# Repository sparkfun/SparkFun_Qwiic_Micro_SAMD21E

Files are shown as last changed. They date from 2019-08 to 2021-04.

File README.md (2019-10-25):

SparkFun Qwiic Micro - SAMD21E
========================================

SAMD21 Qwiic Micro (https://www.sparkfun.com/products/15423)

[*SparkFun Qwiic Micro - SAMD21E (DEV-15423)*](https://www.sparkfun.com/products/15423)

Looking for a super small microcontroller to use with the [Qwiic eco-system](https://www.sparkfun.com/qwiic)? The SparkFun Qwiic Micro is molded to fit our standard 1"x1" Qwiic standard size which makes it one of our smallest micro-controller offerings to date. At it's core is the powerful and versatile ATSAMD21E18, which is an ARM Cortex M0+, 32-bit microcontroller, with 256KB of flash memory that can run at up to 48MHz! It has 12 digital pins which include 5 analog pins, SPI, I²C, and an additional UART data bus as well as a Qwiic connector for easy integration into the Qwiic ecosystem and I²C prototyping.

On the underside of the Qwiic Micro, we've left open pads for a LiPo Battery connector that you can add yourself, if you wish you can make the micro-controller portable. We've also provided pads on the underside for a flash memory chip to maximize the board's memory capacity. The SparkFun Qwiic Micro comes programmed with a UF2 Bootloader making it easy to program with easy driver installation! If you need a tiny but mighty micro-controller for you next project check out the SparkFun Qwiic Micro.

Repository Contents
-------------------

* **/Documentation** - Data sheets, additional product information
* **/Hardware** - Eagle design files (.brd, .sch)
* **/Firmware** - UF2 Bootloader and Arduino Board Files
* **/Production** - Production panel files (.brd)

Documentation
--------------
* **[Hookup Guide](https://learn.sparkfun.com/tutorials/sparkfun-qwiic-micro-samd21e-hookup-guide)** - Basic hookup guide for the Qwiic Micro
* **[Graphical Datasheet](https://github.com/sparkfun/Graphical_Datasheets)** - Graphical datasheet for Qwiic Micro can be found in this repo
* **[Qwiic Ecosystem](https://www.sparkfun.com/qwiic)** - Qwiic enabled for fast prototyping!

License Information
-------------------

This product is _**open source**_! 

Please review the LICENSE.md file for license information. 

If you have any questions or concerns on licensing, please contact technical support on our [SparkFun forums](https://forum.sparkfun.com/viewforum.php?f=152).

Distributed as-is; no warranty is given.

- Your friends at SparkFun.

_<COLLABORATION CREDIT>_

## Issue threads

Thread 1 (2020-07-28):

Pin D16 and D17 are swapped in Board variants.h

NikilXYZ, 2020-07-28:
### Subject of the issue
Pin D16 and D17 are swapped.

### Your workbench
* Using board definition pack 1.7.5

### Steps to reproduce
Go to the variant.cpp file. The 16th entry corresponds to PA22 and 17th to PA23.
According to your [graphical datasheet](https://cdn.sparkfun.com/assets/learn_tutorials/9/1/7/Qwiic_Micro_Graphical_Datasheet.pdf) and your schematic, Pin D16 is PA23 and Pin D17 is PA22.
One of the reviews for this board also noticed the error.

### Expected behaviour
If I `digitalWrite(16, HIGH)` it should turns on Pin 16. `digitalWrite(17, HIGH)` should turn on Pin 17.

### Actual behaviour
Right now, if I `digitalWrite(16, HIGH)` it turns on Pin 17 and `digitalWrite(17, HIGH)` turns on Pin 16.

### Steps to resolve
Go to the variant.cpp file, and flip the 16th entry and 17th entry in the pingroup array.
I did this locally and it works fine, but I cannot tell 100 high school students to go do this.

I can make a pull request if needed

edspark, 2020-07-29:
Thanks for the pull request, it has been merged. As I mentioned in the pull request, I still have to update and do a new release of our Arduino Boards repository before you see it on the Arduino side.

Closed 2020-07-29.

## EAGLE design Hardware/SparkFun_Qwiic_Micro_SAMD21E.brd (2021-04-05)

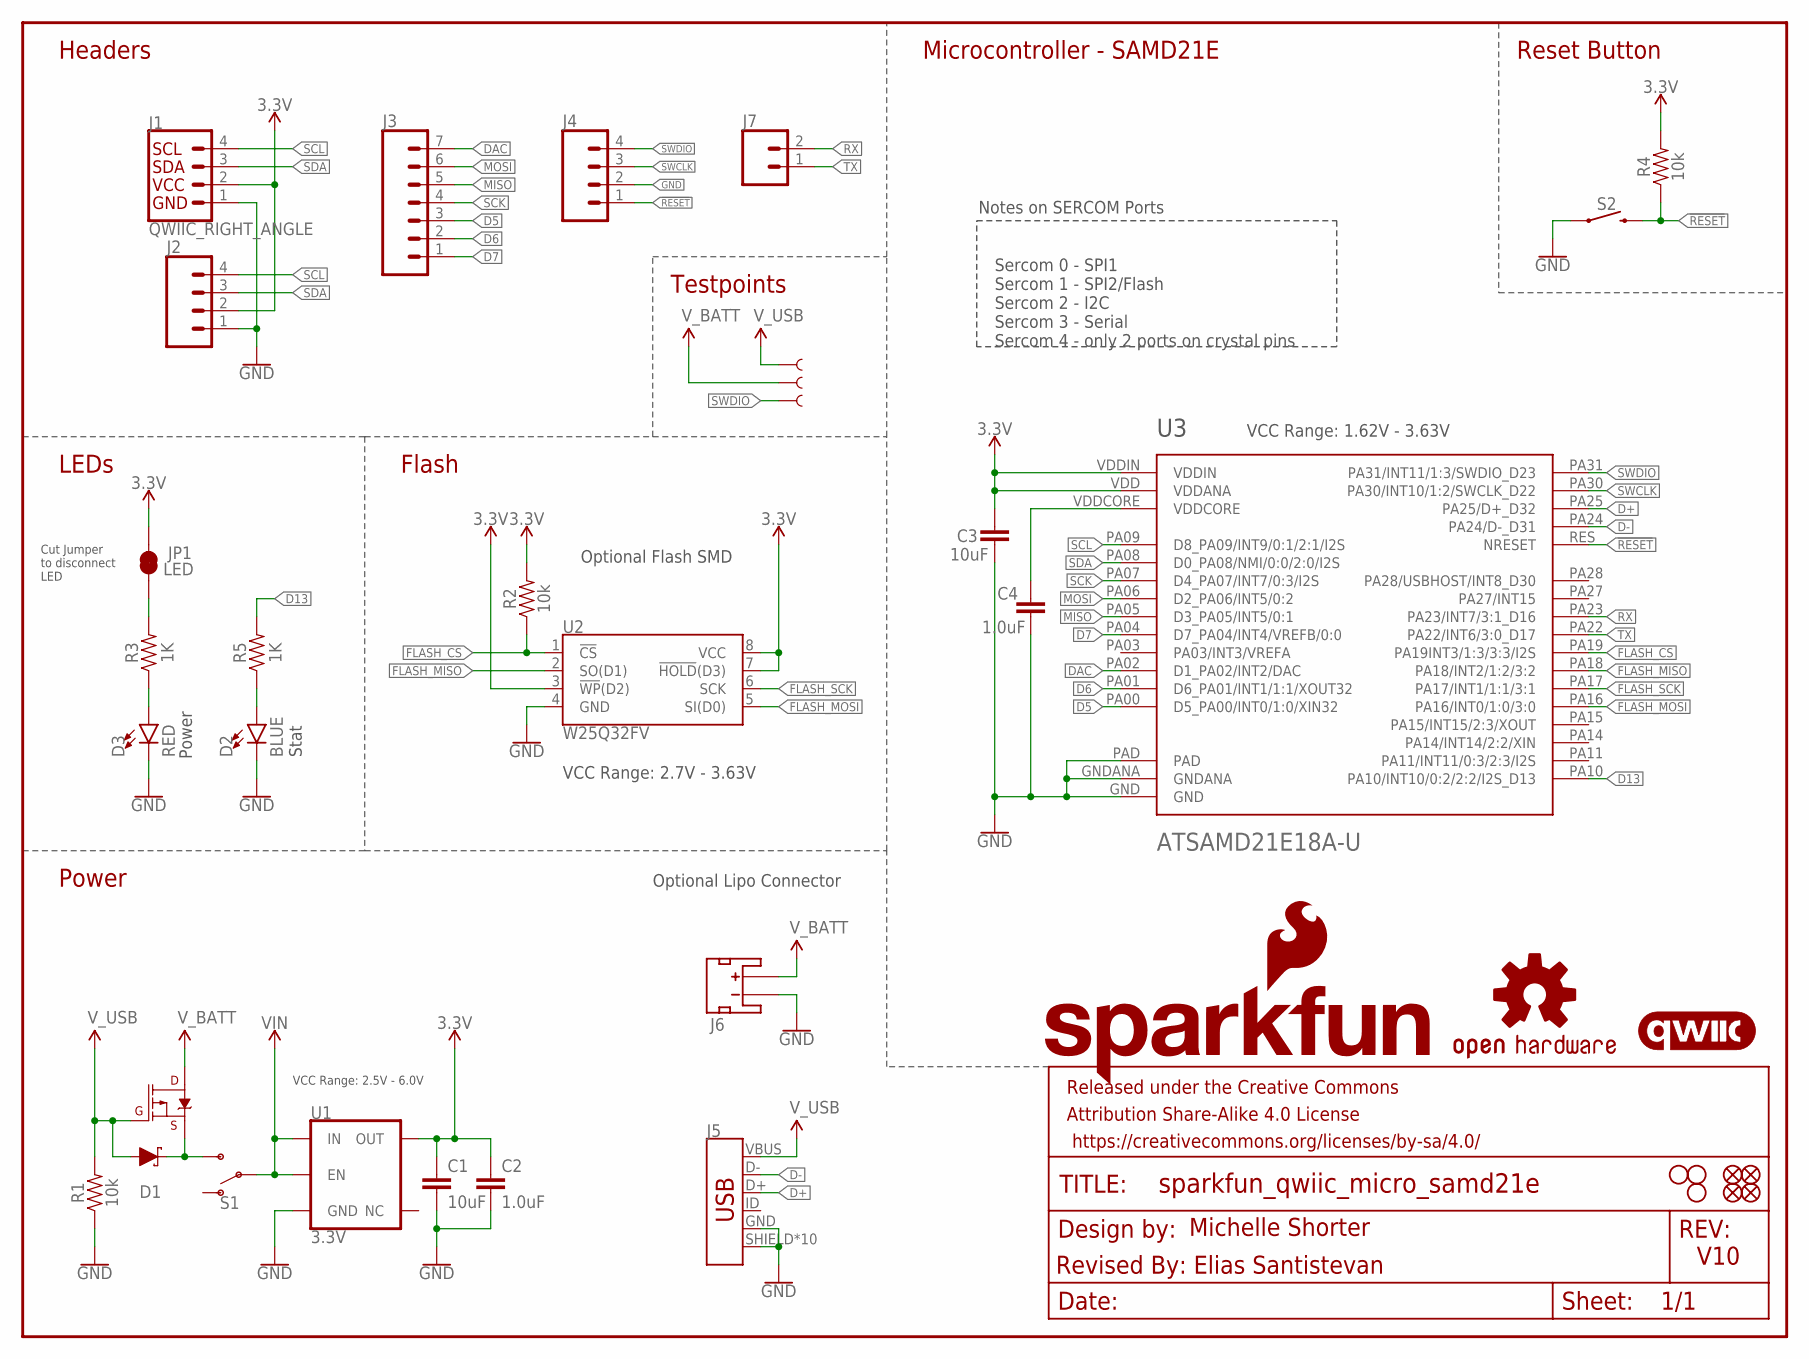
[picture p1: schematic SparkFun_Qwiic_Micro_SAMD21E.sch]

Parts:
C1, C3: 10uF; 0603
C2, C4: 1.0uF; 0402
D1: 1A/23V/620mV; SOD-323
D2: BLUE; LED-0603
D3: RED; LED-0603
FD1, FD2, FD3, FD4: FIDUCIALUFIDUCIAL; FIDUCIAL-MICRO
FRAME1: FRAME-LETTER; CREATIVE_COMMONS
H1, H2, H3: STAND-OFF
J1: QWIIC_RIGHT_ANGLE; JST04_1MM_RA
J2: CONN_041X04_NO_SILK; 1X04_NO_SILK
J3: CONN_07NO_SILK; 1X07_NO_SILK
J4: CONN_041.27MM_NO_SILK; 1X04_1.27MM_NO_SILK
J5: USB_MICRO-B_HALF_PTH_MILL; USB-MICROB-PTH-MILL
J6: JST_2MM_MALE; JST-2-SMD
J7: CONN_021X02_NO_SILK; 1X02_NO_SILK
JP1: LED; SMT-JUMPER_2_NC_TRACE_SILK
LOGO1: SFE_LOGO_NAME.1_INCH; SFE_LOGO_NAME_.1
LOGO2: SFE_LOGO_FLAME.2_INCH; SFE_LOGO_FLAME_.2
LOGO3: OSHW-LOGOS; OSHW-LOGO-S
LOGO4: QWIIC_LOGO_3MM; QWIIC_3MM
Q1: 3.1A/30V/105mΩ; SOT23-3
R1, R2, R4: 10k; 0402
R3, R5: 1K; 0402
S1: SWITCH-SPDT-SMD-RIGHT-ANGLE; SWITCH_SPST_SMD_A
S2: MOMENTARY-SWITCH-SPST-SMD-4.6X2.8MM; TACTILE_SWITCH_SMD_4.6X2.8MM
TP1, TP2, TP3: TEST-POINTTP_15TH_THRU; TP_15TH
U1: 3.3V; SOT23-5
U2: W25Q32FV; SOIC-8
U3: ATSAMD21E18A-U; QFN-32_SAMD

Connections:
3.3V: C1.1, C2.1, C3.1, J1.2, J2.2, JP1.2, R2.2, R4.2, U1.5 (OUT), U2.3 (!WP!(D2)), U2.7 (!HOLD!(D3)), U2.8 (VCC), U3.VDD (VDDANA), U3.VDDIN
!RESET: J4.1, R4.1, S2.3 (2), S2.4 (2), U3.RES (NRESET)
D5: J3.3, U3.PA00 (D5_PA00/INT0/1:0/XIN32)
D6: J3.2, U3.PA01 (D6_PA01/INT1/1:1/XOUT32)
D7: J3.1, U3.PA04 (D7_PA04/INT4/VREFB/0:0)
D13: R5.2, U3.PA10 (PA10/INT10/0:2/2:2/I2S_D13)
D+: J5.D+, U3.PA25 (PA25/D+_D32)
D-: J5.D-, U3.PA24 (PA24/D-_D31)
DAC: J3.7, U3.PA02 (D1_PA02/INT2/DAC)
FLASH_CS: R2.1, U2.1 (!CS!), U3.PA19 (PA19INT3/1:3/3:3/I2S)
FLASH_MISO: U2.2 (SO(D1)), U3.PA18 (PA18/INT2/1:2/3:2)
FLASH_MOSI: U2.5 (SI(D0)), U3.PA16 (PA16/INT0/1:0/3:0)
FLASH_SCK: U2.6 (SCK), U3.PA17 (PA17/INT1/1:1/3:1)
GND: C1.2, C2.2, C3.2, C4.1, D2.C, D3.C, J1.1, J2.1, J4.2, J5.GND, J5.SHIELD, J5.SHIELD2 (SHIELD), J5.SHIELD3 (SHIELD), J5.SHIELD4 (SHIELD), J5.SHIELD5 (SHIELD), J5.SHIELD6 (SHIELD), J5.SHIELD7 (SHIELD), J5.SHIELD8 (SHIELD), J5.SHIELD9 (SHIELD), J5.SHIELD10 (SHIELD), J6.1 (-), R1.1, S2.1, S2.2 (1), U1.2 (GND), U2.4 (GND), U3.GND, U3.GNDANA, U3.PAD
MISO: J3.5, U3.PA05 (D3_PA05/INT5/0:1)
MOSI: J3.6, U3.PA06 (D2_PA06/INT5/0:2)
unnamed: D3.A, R3.1
unnamed: JP1.1, R3.2
unnamed: D2.A, R5.1
RX: J7.2, U3.PA23 (PA23/INT7/3:1_D16)
SCK: J3.4, U3.PA07 (D4_PA07/INT7/0:3/I2S)
SCL: J1.4, J2.4, U3.PA09 (D8_PA09/INT9/0:1/2:1/I2S)
SDA: J1.3, J2.3, U3.PA08 (D0_PA08/NMI/0:0/2:0/I2S)
SWCLK: J4.3, U3.PA30 (PA30/INT10/1:2/SWCLK_D22)
SWDIO: J4.4, TP3.P$1, U3.PA31 (PA31/INT11/1:3/SWDIO_D23)
TX: J7.1, U3.PA22 (PA22/INT6/3:0_D17)
VDDCORE: C4.2, U3.VDDCORE
VIN: S1.2, U1.1 (IN), U1.3 (EN)
VIN1: D1.C, Q1.2 (S), S1.3 (S)
V_BATT: J6.2 (+), Q1.3 (D), TP2.P$1
V_USB: D1.A, J5.VBUS, Q1.1 (G), R1.2, TP1.P$1

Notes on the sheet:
Sercom 0 - SPI1 Sercom 1 - SPI2/Flash Sercom 2 - I2C Sercom 3 - Serial Sercom 4 - only 2 ports on crystal pins
Headers
LEDs
Power
Microcontroller - SAMD21E
Optional Flash SMD
V10
Michelle Shorter
Revised By: Elias Santistevan
Testpoints
Reset Button
Flash
Cut Jumper to disconnect LED
Notes on SERCOM Ports
Stat
VCC Range: 2.5V - 6.0V
VCC Range: 1.62V - 3.63V
VCC Range: 2.7V - 3.63V
Optional Lipo Connector

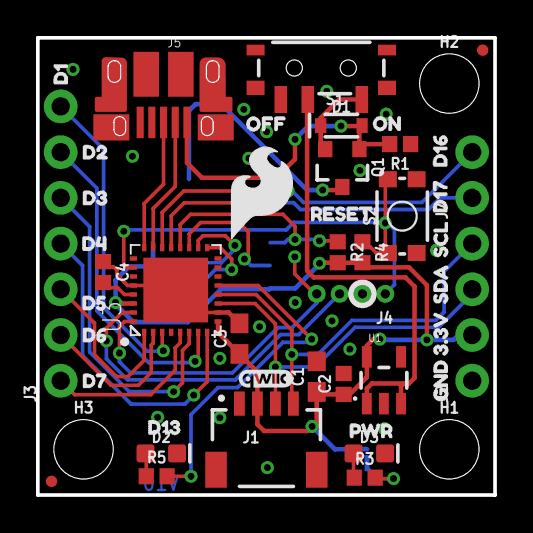
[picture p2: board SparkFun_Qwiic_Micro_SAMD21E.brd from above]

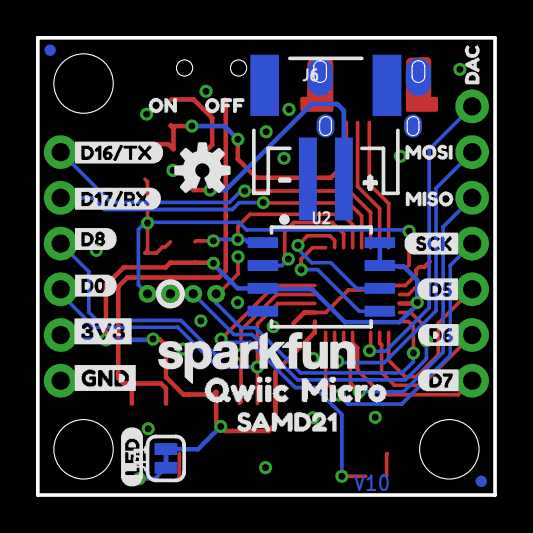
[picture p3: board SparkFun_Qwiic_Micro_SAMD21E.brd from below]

Board: 2 copper layers, 25.4 x 25.4 mm, 80 parts (28 on the bottom side), 31 nets.

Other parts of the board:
U$1: D00
U$2: GND-03
U$3: #23
U$4: #24
U$5: 3#3V10
U$6: D12
U$7: D166
U$8: D177
U$9: D16#TX4
U$10: QWIIC2
U$11: D17#RX3
U$12: D75
U$13: DAC1
U$14: MISO0
U$15: SAMD213
U$16: MOSI2
U$17: 3V3-03
U$18, U$46: ON12
U$19, U$45: OFF13
U$20: SCK7
U$21: RESET0
U$22: D85
U$23: MICRO2
U$24: LED1
U$25: D50
U$26: D61
U$27: D72
U$28: D21
U$29: D136
U$36: D33
U$37: D41
U$38: D52
U$39: D65
U$44: GND11
U$47: PWR16
U$49: SCL8
U$50: SDA9

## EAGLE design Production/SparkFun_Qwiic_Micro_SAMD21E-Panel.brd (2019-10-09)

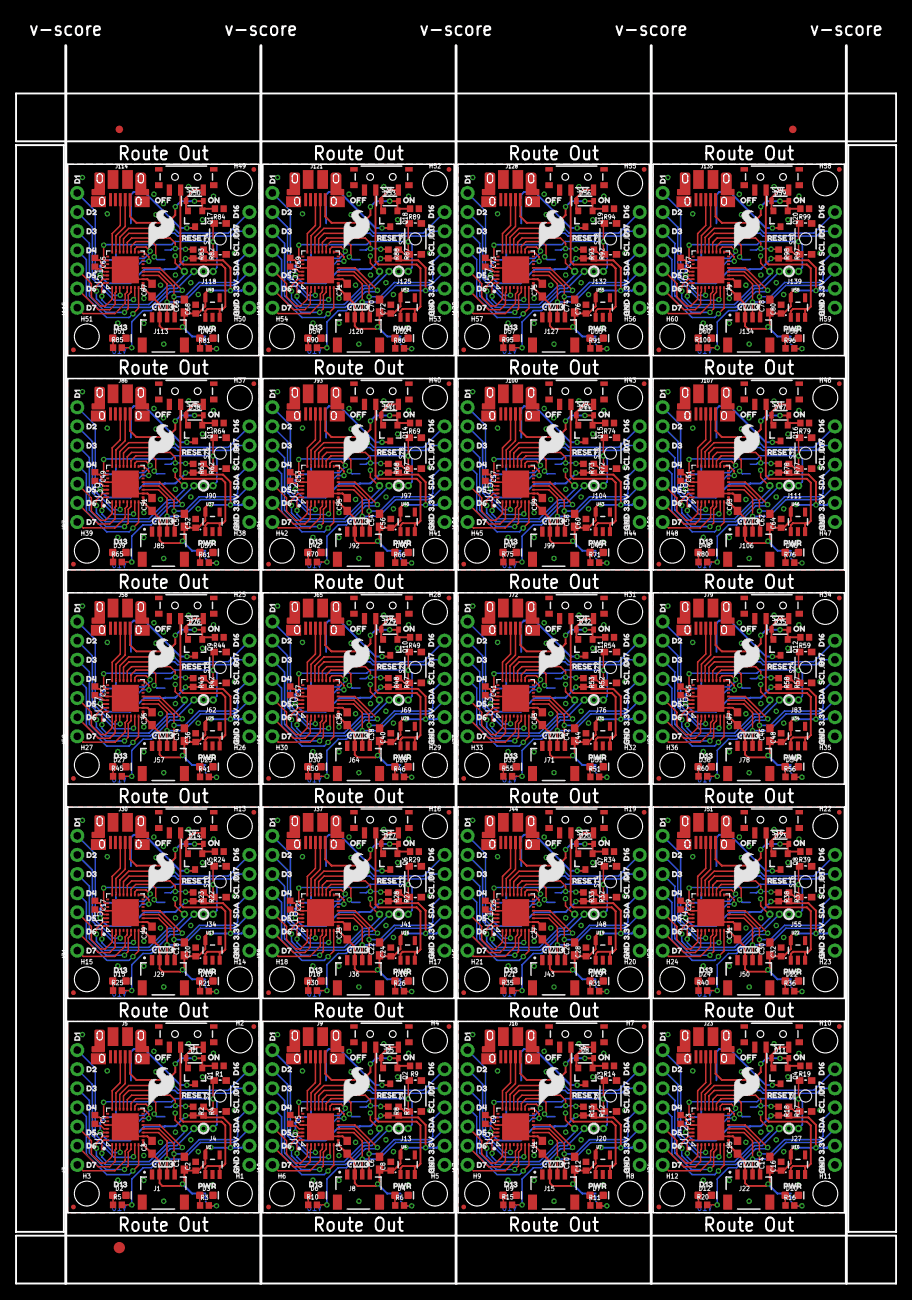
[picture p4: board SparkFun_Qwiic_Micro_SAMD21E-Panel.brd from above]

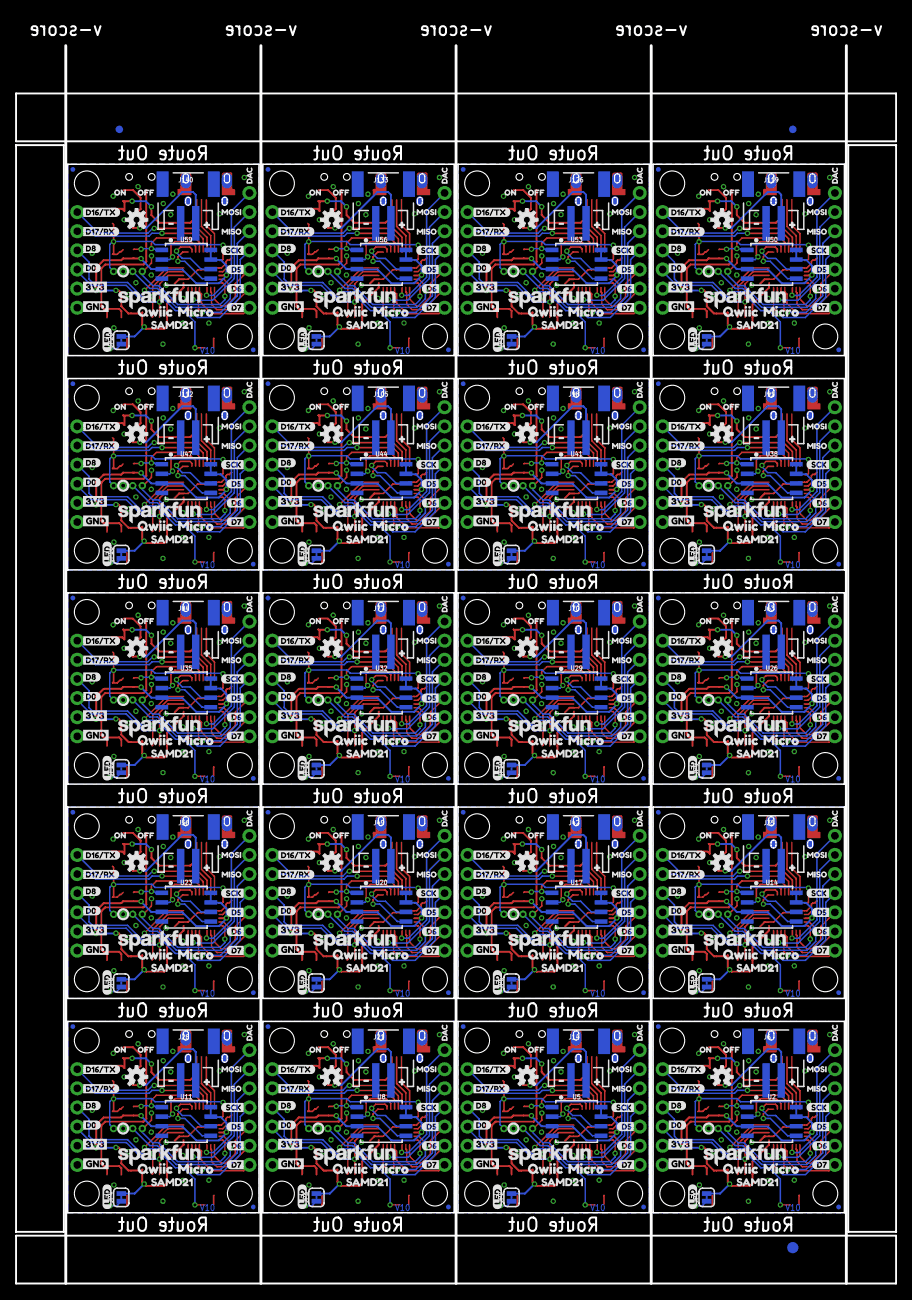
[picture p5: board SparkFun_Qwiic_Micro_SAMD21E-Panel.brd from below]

Board: 2 copper layers, 116.8 x 164.3 mm, 1586 parts (563 on the bottom side), 620 nets.

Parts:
C1, C3, C6, C7, C10, C11, C14, C15, C18, C19, C22, C23, C26, C27, C30, C31, C34, C35, C38, C39, C42, C43, C46, C47, C50, C51, C54, C55, C58, C59, C62, C63, C66, C67, C70, C71, C74, C75, C78, C79: 10uF; 0603
C2, C4, C5, C8, C9, C12, C13, C16, C17, C20, C21, C24, C25, C28, C29, C32, C33, C36, C37, C40, C41, C44, C45, C48, C49, C52, C53, C56, C57, C60, C61, C64, C65, C68, C69, C72, C73, C76, C77, C80: 1.0uF; 0402
D1, D5, D8, D11, D14, D17, D20, D23, D26, D29, D32, D35, D38, D41, D44, D47, D50, D53, D56, D59: 1A/23V/620mV; SOD-323
D2, D6, D9, D12, D15, D18, D21, D24, D27, D30, D33, D36, D39, D42, D45, D48, D51, D54, D57, D60: BLUE; LED-0603
D3, D4, D7, D10, D13, D16, D19, D22, D25, D28, D31, D34, D37, D40, D43, D46, D49, D52, D55, D58: RED; LED-0603
E$1, E$2, E$3, E$4: FIDUCIAL-1X2
E$5, E$6: FIDUCIAL-1.5X3
FD1, FD2, FD3, FD4, FD5, FD6, FD7, FD8, FD9, FD10, FD11, FD12, FD13, FD14, FD15, FD16, FD17, FD18, FD19, FD20, FD21, FD22, FD23, FD24, FD25, FD26, FD27, FD28, FD29, FD30, FD31, FD32, FD33, FD34, FD35, FD36, FD37, FD38, FD39, FD40, FD41, FD42, FD43, FD44, FD45, FD46, FD47, FD48, FD49, FD50, FD51, FD52, FD53, FD54, FD55, FD56, FD57, FD58, FD59, FD60, FD61, FD62, FD63, FD64, FD65, FD66, FD67, FD68, FD69, FD70, FD71, FD72, FD73, FD74, FD75, FD76, FD77, FD78, FD79, FD80: FIDUCIALUFIDUCIAL; FIDUCIAL-MICRO
H1, H2, H3, H4, H5, H6, H7, H8, H9, H10, H11, H12, H13, H14, H15, H16, H17, H18, H19, H20, H21, H22, H23, H24, H25, H26, H27, H28, H29, H30, H31, H32, H33, H34, H35, H36, H37, H38, H39, H40, H41, H42, H43, H44, H45, H46, H47, H48, H49, H50, H51, H52, H53, H54, H55, H56, H57, H58, H59, H60: STAND-OFF
J1, J8, J15, J22, J29, J36, J43, J50, J57, J64, J71, J78, J85, J92, J99, J106, J113, J120, J127, J134: JST04_1MM_RA
J2, J12, J19, J26, J33, J40, J47, J54, J61, J68, J75, J82, J89, J96, J103, J110, J117, J124, J131, J138: 1X04_NO_SILK
J3, J10, J17, J24, J31, J38, J45, J52, J59, J66, J73, J80, J87, J94, J101, J108, J115, J122, J129, J136: 1X07_NO_SILK
J4, J13, J20, J27, J34, J41, J48, J55, J62, J69, J76, J83, J90, J97, J104, J111, J118, J125, J132, J139: 1X04_1.27MM_NO_SILK
J5, J9, J16, J23, J30, J37, J44, J51, J58, J65, J72, J79, J86, J93, J100, J107, J114, J121, J128, J135: USB-MICROB-PTH-MILL
J6, J14, J21, J28, J35, J42, J49, J56, J63, J70, J77, J84, J91, J98, J105, J112, J119, J126, J133, J140: JST-2-SMD
J7, J11, J18, J25, J32, J39, J46, J53, J60, J67, J74, J81, J88, J95, J102, J109, J116, J123, J130, J137: 1X02_NO_SILK
JP1, JP2, JP3, JP4, JP5, JP6, JP7, JP8, JP9, JP10, JP11, JP12, JP13, JP14, JP15, JP16, JP17, JP18, JP19, JP20: LED; SMT-JUMPER_2_NC_TRACE_SILK
LOGO1, LOGO7, LOGO11, LOGO15, LOGO19, LOGO23, LOGO27, LOGO31, LOGO35, LOGO39, LOGO43, LOGO47, LOGO51, LOGO55, LOGO59, LOGO63, LOGO67, LOGO71, LOGO75, LOGO79: SFE_LOGO_NAME.1_INCH; SFE_LOGO_NAME_.1
LOGO2, LOGO6, LOGO10, LOGO14, LOGO18, LOGO22, LOGO26, LOGO30, LOGO34, LOGO38, LOGO42, LOGO46, LOGO50, LOGO54, LOGO58, LOGO62, LOGO66, LOGO70, LOGO74, LOGO78: SFE_LOGO_FLAME.2_INCH; SFE_LOGO_FLAME_.2
LOGO3, LOGO5, LOGO9, LOGO13, LOGO17, LOGO21, LOGO25, LOGO29, LOGO33, LOGO37, LOGO41, LOGO45, LOGO49, LOGO53, LOGO57, LOGO61, LOGO65, LOGO69, LOGO73, LOGO77: OSHW-LOGOS; OSHW-LOGO-S
LOGO4, LOGO8, LOGO12, LOGO16, LOGO20, LOGO24, LOGO28, LOGO32, LOGO36, LOGO40, LOGO44, LOGO48, LOGO52, LOGO56, LOGO60, LOGO64, LOGO68, LOGO72, LOGO76, LOGO80: QWIIC_LOGO_3MM; QWIIC_3MM
Q1, Q2, Q3, Q4, Q5, Q6, Q7, Q8, Q9, Q10, Q11, Q12, Q13, Q14, Q15, Q16, Q17, Q18, Q19, Q20: 3.1A/30V/105mΩ; SOT23-3
R1, R2, R4, R7, R8, R9, R12, R13, R14, R17, R18, R19, R22, R23, R24, R27, R28, R29, R32, R33, R34, R37, R38, R39, R42, R43, R44, R47, R48, R49, R52, R53, R54, R57, R58, R59, R62, R63, R64, R67, R68, R69, R72, R73, R74, R77, R78, R79, R82, R83, R84, R87, R88, R89, R92, R93, R94, R97, R98, R99: 10k; 0402
R3, R5, R6, R10, R11, R15, R16, R20, R21, R25, R26, R30, R31, R35, R36, R40, R41, R45, R46, R50, R51, R55, R56, R60, R61, R65, R66, R70, R71, R75, R76, R80, R81, R85, R86, R90, R91, R95, R96, R100: 1K; 0402
S1, S3, S5, S7, S9, S11, S13, S15, S17, S19, S21, S23, S25, S27, S29, S31, S33, S35, S37, S39: SWITCH_SPST_SMD_A
S2, S4, S6, S8, S10, S12, S14, S16, S18, S20, S22, S24, S26, S28, S30, S32, S34, S36, S38, S40: MOMENTARY-SWITCH-SPST-SMD-4.6X2.8MM; TACTILE_SWITCH_SMD_4.6X2.8MM
TP1, TP2, TP3, TP4, TP5, TP6, TP7, TP8, TP9, TP10, TP11, TP12, TP13, TP14, TP15, TP16, TP17, TP18, TP19, TP20, TP21, TP22, TP23, TP24, TP25, TP26, TP27, TP28, TP29, TP30, TP31, TP32, TP33, TP34, TP35, TP36, TP37, TP38, TP39, TP40, TP41, TP42, TP43, TP44, TP45, TP46, TP47, TP48, TP49, TP50, TP51, TP52, TP53, TP54, TP55, TP56, TP57, TP58, TP59, TP60: TEST-POINTTP_15TH_THRU; TP_15TH
U1, U4, U7, U10, U13, U16, U19, U22, U25, U28, U31, U34, U37, U40, U43, U46, U49, U52, U55, U58: 3.3V; SOT23-5
U2, U5, U8, U11, U14, U17, U20, U23, U26, U29, U32, U35, U38, U41, U44, U47, U50, U53, U56, U59: W25Q32FV; SOIC-8
U3, U6, U9, U12, U15, U18, U21, U24, U27, U30, U33, U36, U39, U42, U45, U48, U51, U54, U57, U60: ATSAMD21E18A-U; QFN-32_SAMD
U$1, U$59, U$98, U$137, U$176, U$215, U$254, U$293, U$332, U$371, U$410, U$449, U$488, U$527, U$566, U$605, U$644, U$683, U$722, U$761: D00
U$2, U$64, U$103, U$142, U$181, U$220, U$259, U$298, U$337, U$376, U$415, U$454, U$493, U$532, U$571, U$610, U$649, U$688, U$727, U$766: GND-03
U$3, U$30, U$79, U$118, U$157, U$196, U$235, U$274, U$313, U$352, U$391, U$430, U$469, U$508, U$547, U$586, U$625, U$664, U$703, U$742: #23
U$4, U$31, U$80, U$119, U$158, U$197, U$236, U$275, U$314, U$353, U$392, U$431, U$470, U$509, U$548, U$587, U$626, U$665, U$704, U$743: #24
U$5, U$32, U$81, U$120, U$159, U$198, U$237, U$276, U$315, U$354, U$393, U$432, U$471, U$510, U$549, U$588, U$627, U$666, U$705, U$744: 3#3V10
U$6, U$60, U$99, U$138, U$177, U$216, U$255, U$294, U$333, U$372, U$411, U$450, U$489, U$528, U$567, U$606, U$645, U$684, U$723, U$762: D12
U$7, U$70, U$109, U$148, U$187, U$226, U$265, U$304, U$343, U$382, U$421, U$460, U$499, U$538, U$577, U$616, U$655, U$694, U$733, U$772: D166
U$8, U$71, U$110, U$149, U$188, U$227, U$266, U$305, U$344, U$383, U$422, U$461, U$500, U$539, U$578, U$617, U$656, U$695, U$734, U$773: D177
U$9, U$72, U$111, U$150, U$189, U$228, U$267, U$306, U$345, U$384, U$423, U$462, U$501, U$540, U$579, U$618, U$657, U$696, U$735, U$774: D16#TX4
U$10, U$61, U$100, U$139, U$178, U$217, U$256, U$295, U$334, U$373, U$412, U$451, U$490, U$529, U$568, U$607, U$646, U$685, U$724, U$763: QWIIC2
U$11, U$73, U$112, U$151, U$190, U$229, U$268, U$307, U$346, U$385, U$424, U$463, U$502, U$541, U$580, U$619, U$658, U$697, U$736, U$775: D17#RX3
U$12, U$66, U$105, U$144, U$183, U$222, U$261, U$300, U$339, U$378, U$417, U$456, U$495, U$534, U$573, U$612, U$651, U$690, U$729, U$768: D75
U$13, U$67, U$106, U$145, U$184, U$223, U$262, U$301, U$340, U$379, U$418, U$457, U$496, U$535, U$574, U$613, U$652, U$691, U$730, U$769: DAC1
U$14, U$55, U$94, U$133, U$172, U$211, U$250, U$289, U$328, U$367, U$406, U$445, U$484, U$523, U$562, U$601, U$640, U$679, U$718, U$757: MISO0
U$15, U$63, U$102, U$141, U$180, U$219, U$258, U$297, U$336, U$375, U$414, U$453, U$492, U$531, U$570, U$609, U$648, U$687, U$726, U$765: SAMD213
U$16, U$68, U$107, U$146, U$185, U$224, U$263, U$302, U$341, U$380, U$419, U$458, U$497, U$536, U$575, U$614, U$653, U$692, U$731, U$770: MOSI2
U$17, U$65, U$104, U$143, U$182, U$221, U$260, U$299, U$338, U$377, U$416, U$455, U$494, U$533, U$572, U$611, U$650, U$689, U$728, U$767: 3V3-03
U$18, U$43, U$46, U$57, U$88, U$96, U$127, U$135, U$166, U$174, U$205, U$213, U$244, U$252, U$283, U$291, U$322, U$330, U$361, U$369, U$400, U$408, U$439, U$447, U$478, U$486, U$517, U$525, U$556, U$564, U$595, U$603, U$634, U$642, U$673, U$681, U$712, U$720, U$751, U$759: ON12
U$19, U$42, U$45, U$58, U$87, U$97, U$126, U$136, U$165, U$175, U$204, U$214, U$243, U$253, U$282, U$292, U$321, U$331, U$360, U$370, U$399, U$409, U$438, U$448, U$477, U$487, U$516, U$526, U$555, U$565, U$594, U$604, U$633, U$643, U$672, U$682, U$711, U$721, U$750, U$760: OFF13
U$20, U$54, U$93, U$132, U$171, U$210, U$249, U$288, U$327, U$366, U$405, U$444, U$483, U$522, U$561, U$600, U$639, U$678, U$717, U$756: SCK7
U$21, U$53, U$92, U$131, U$170, U$209, U$248, U$287, U$326, U$365, U$404, U$443, U$482, U$521, U$560, U$599, U$638, U$677, U$716, U$755: RESET0
U$22, U$74, U$113, U$152, U$191, U$230, U$269, U$308, U$347, U$386, U$425, U$464, U$503, U$542, U$581, U$620, U$659, U$698, U$737, U$776: D85
U$23, U$62, U$101, U$140, U$179, U$218, U$257, U$296, U$335, U$374, U$413, U$452, U$491, U$530, U$569, U$608, U$647, U$686, U$725, U$764: MICRO2
U$24, U$56, U$95, U$134, U$173, U$212, U$251, U$290, U$329, U$368, U$407, U$446, U$485, U$524, U$563, U$602, U$641, U$680, U$719, U$758: LED1
U$25, U$75, U$114, U$153, U$192, U$231, U$270, U$309, U$348, U$387, U$426, U$465, U$504, U$543, U$582, U$621, U$660, U$699, U$738, U$777: D50
U$26, U$76, U$115, U$154, U$193, U$232, U$271, U$310, U$349, U$388, U$427, U$466, U$505, U$544, U$583, U$622, U$661, U$700, U$739, U$778: D61
U$27, U$77, U$116, U$155, U$194, U$233, U$272, U$311, U$350, U$389, U$428, U$467, U$506, U$545, U$584, U$623, U$662, U$701, U$740, U$779: D72
U$28, U$69, U$108, U$147, U$186, U$225, U$264, U$303, U$342, U$381, U$420, U$459, U$498, U$537, U$576, U$615, U$654, U$693, U$732, U$771: D21
U$29, U$78, U$117, U$156, U$195, U$234, U$273, U$312, U$351, U$390, U$429, U$468, U$507, U$546, U$585, U$624, U$663, U$702, U$741, U$780: D136
U$33, U$36, U$82, U$121, U$160, U$199, U$238, U$277, U$316, U$355, U$394, U$433, U$472, U$511, U$550, U$589, U$628, U$667, U$706, U$745: D33
U$34, U$37, U$83, U$122, U$161, U$200, U$239, U$278, U$317, U$356, U$395, U$434, U$473, U$512, U$551, U$590, U$629, U$668, U$707, U$746: D41
U$35, U$38, U$84, U$123, U$162, U$201, U$240, U$279, U$318, U$357, U$396, U$435, U$474, U$513, U$552, U$591, U$630, U$669, U$708, U$747: D52
U$39, U$40, U$85, U$124, U$163, U$202, U$241, U$280, U$319, U$358, U$397, U$436, U$475, U$514, U$553, U$592, U$631, U$670, U$709, U$748: D65
U$41, U$44, U$86, U$125, U$164, U$203, U$242, U$281, U$320, U$359, U$398, U$437, U$476, U$515, U$554, U$593, U$632, U$671, U$710, U$749: GND11
U$47, U$48, U$89, U$128, U$167, U$206, U$245, U$284, U$323, U$362, U$401, U$440, U$479, U$518, U$557, U$596, U$635, U$674, U$713, U$752: PWR16
U$49, U$51, U$90, U$129, U$168, U$207, U$246, U$285, U$324, U$363, U$402, U$441, U$480, U$519, U$558, U$597, U$636, U$675, U$714, U$753: SCL8
U$50, U$52, U$91, U$130, U$169, U$208, U$247, U$286, U$325, U$364, U$403, U$442, U$481, U$520, U$559, U$598, U$637, U$676, U$715, U$754: SDA9

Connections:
3.3V: C1.1, C2.1, C3.1, J1.2, J2.2, JP1.2, R2.2, R4.2, U1.5, U2.3, U2.7, U2.8, U3.VDD, U3.VDDIN
3.3V1: C6.1, C7.1, C8.1, J8.2, J12.2, JP2.2, R7.2, R8.2, U4.5, U5.3, U5.7, U5.8, U6.VDD, U6.VDDIN
3.3V2: C10.1, C11.1, C12.1, J15.2, J19.2, JP3.2, R12.2, R13.2, U7.5, U8.3, U8.7, U8.8, U9.VDD, U9.VDDIN
3.3V3: C14.1, C15.1, C16.1, J22.2, J26.2, JP4.2, R17.2, R18.2, U10.5, U11.3, U11.7, U11.8, U12.VDD, U12.VDDIN
3.3V4: C18.1, C19.1, C20.1, J29.2, J33.2, JP5.2, R22.2, R23.2, U13.5, U14.3, U14.7, U14.8, U15.VDD, U15.VDDIN
3.3V5: C22.1, C23.1, C24.1, J36.2, J40.2, JP6.2, R27.2, R28.2, U16.5, U17.3, U17.7, U17.8, U18.VDD, U18.VDDIN
3.3V6: C26.1, C27.1, C28.1, J43.2, J47.2, JP7.2, R32.2, R33.2, U19.5, U20.3, U20.7, U20.8, U21.VDD, U21.VDDIN
3.3V7: C30.1, C31.1, C32.1, J50.2, J54.2, JP8.2, R37.2, R38.2, U22.5, U23.3, U23.7, U23.8, U24.VDD, U24.VDDIN
3.3V8: C34.1, C35.1, C36.1, J57.2, J61.2, JP9.2, R42.2, R43.2, U25.5, U26.3, U26.7, U26.8, U27.VDD, U27.VDDIN
3.3V9: C38.1, C39.1, C40.1, J64.2, J68.2, JP10.2, R47.2, R48.2, U28.5, U29.3, U29.7, U29.8, U30.VDD, U30.VDDIN
3.3V10: C42.1, C43.1, C44.1, J71.2, J75.2, JP11.2, R52.2, R53.2, U31.5, U32.3, U32.7, U32.8, U33.VDD, U33.VDDIN
3.3V11: C46.1, C47.1, C48.1, J78.2, J82.2, JP12.2, R57.2, R58.2, U34.5, U35.3, U35.7, U35.8, U36.VDD, U36.VDDIN
3.3V12: C50.1, C51.1, C52.1, J85.2, J89.2, JP13.2, R62.2, R63.2, U37.5, U38.3, U38.7, U38.8, U39.VDD, U39.VDDIN
3.3V13: C54.1, C55.1, C56.1, J92.2, J96.2, JP14.2, R67.2, R68.2, U40.5, U41.3, U41.7, U41.8, U42.VDD, U42.VDDIN
3.3V14: C58.1, C59.1, C60.1, J99.2, J103.2, JP15.2, R72.2, R73.2, U43.5, U44.3, U44.7, U44.8, U45.VDD, U45.VDDIN
3.3V15: C62.1, C63.1, C64.1, J106.2, J110.2, JP16.2, R77.2, R78.2, U46.5, U47.3, U47.7, U47.8, U48.VDD, U48.VDDIN
3.3V16: C66.1, C67.1, C68.1, J113.2, J117.2, JP17.2, R82.2, R83.2, U49.5, U50.3, U50.7, U50.8, U51.VDD, U51.VDDIN
3.3V17: C70.1, C71.1, C72.1, J120.2, J124.2, JP18.2, R87.2, R88.2, U52.5, U53.3, U53.7, U53.8, U54.VDD, U54.VDDIN
3.3V18: C74.1, C75.1, C76.1, J127.2, J131.2, JP19.2, R92.2, R93.2, U55.5, U56.3, U56.7, U56.8, U57.VDD, U57.VDDIN
3.3V19: C78.1, C79.1, C80.1, J134.2, J138.2, JP20.2, R97.2, R98.2, U58.5, U59.3, U59.7, U59.8, U60.VDD, U60.VDDIN
!RESET: J4.1, R4.1, S2.3, S2.4, U3.RES
!RESET1: J13.1, R7.1, S4.3, S4.4, U6.RES
!RESET2: J20.1, R12.1, S6.3, S6.4, U9.RES
!RESET3: J27.1, R17.1, S8.3, S8.4, U12.RES
!RESET4: J34.1, R22.1, S10.3, S10.4, U15.RES
!RESET5: J41.1, R27.1, S12.3, S12.4, U18.RES
!RESET6: J48.1, R32.1, S14.3, S14.4, U21.RES
!RESET7: J55.1, R37.1, S16.3, S16.4, U24.RES
!RESET8: J62.1, R42.1, S18.3, S18.4, U27.RES
!RESET9: J69.1, R47.1, S20.3, S20.4, U30.RES
!RESET10: J76.1, R52.1, S22.3, S22.4, U33.RES
!RESET11: J83.1, R57.1, S24.3, S24.4, U36.RES
!RESET12: J90.1, R62.1, S26.3, S26.4, U39.RES
!RESET13: J97.1, R67.1, S28.3, S28.4, U42.RES
!RESET14: J104.1, R72.1, S30.3, S30.4, U45.RES
!RESET15: J111.1, R77.1, S32.3, S32.4, U48.RES
!RESET16: J118.1, R82.1, S34.3, S34.4, U51.RES
!RESET17: J125.1, R87.1, S36.3, S36.4, U54.RES
!RESET18: J132.1, R92.1, S38.3, S38.4, U57.RES
!RESET19: J139.1, R97.1, S40.3, S40.4, U60.RES
D1: J10.1, U6.PA04
D2: J10.3, U6.PA00
D3: R10.2, U6.PA10
D4: J10.2, U6.PA01
D5: J3.3, U3.PA00
D6: J3.2, U3.PA01
D7: J3.1, U3.PA04
D8: J17.1, U9.PA04
D9: J17.3, U9.PA00
D10: R15.2, U9.PA10
D11: J17.2, U9.PA01
D12: J24.1, U12.PA04
D13: R5.2, U3.PA10
D14: J24.3, U12.PA00
D15: R20.2, U12.PA10
D16: J24.2, U12.PA01
D17: J31.1, U15.PA04
D18: J31.3, U15.PA00
D19: R25.2, U15.PA10
D20: J31.2, U15.PA01
D21: J38.1, U18.PA04
D22: J38.3, U18.PA00
D23: R30.2, U18.PA10
D24: J38.2, U18.PA01
D25: J45.1, U21.PA04
D26: J45.3, U21.PA00
D27: R35.2, U21.PA10
D28: J45.2, U21.PA01
D29: J52.1, U24.PA04
D30: J52.3, U24.PA00
D31: R40.2, U24.PA10
D32: J52.2, U24.PA01
D33: J59.1, U27.PA04
D34: J59.3, U27.PA00
D35: R45.2, U27.PA10
D36: J59.2, U27.PA01
D37: J66.1, U30.PA04
D38: J66.3, U30.PA00
D39: R50.2, U30.PA10
D40: J66.2, U30.PA01
D41: J73.1, U33.PA04
D42: J73.3, U33.PA00
D43: R55.2, U33.PA10
D44: J73.2, U33.PA01
D45: J80.1, U36.PA04
D46: J80.3, U36.PA00
D47: R60.2, U36.PA10
D48: J80.2, U36.PA01
D49: J87.1, U39.PA04
D50: J87.3, U39.PA00
D51: R65.2, U39.PA10
D52: J87.2, U39.PA01
D53: J94.1, U42.PA04
D54: J94.3, U42.PA00
D55: R70.2, U42.PA10
D56: J94.2, U42.PA01
D57: J101.1, U45.PA04
D58: J101.3, U45.PA00
D59: R75.2, U45.PA10
D60: J101.2, U45.PA01
D61: J108.1, U48.PA04
D62: J108.3, U48.PA00
D63: R80.2, U48.PA10
D64: J108.2, U48.PA01
D65: J115.1, U51.PA04
D66: J115.3, U51.PA00
D67: R85.2, U51.PA10
D68: J115.2, U51.PA01
D69: J122.1, U54.PA04
D70: J122.3, U54.PA00
D71: R90.2, U54.PA10
D72: J122.2, U54.PA01
D73: J129.1, U57.PA04
D74: J129.3, U57.PA00
D75: R95.2, U57.PA10
D76: J129.2, U57.PA01
D77: J136.1, U60.PA04
D78: J136.3, U60.PA00
D79: R100.2, U60.PA10
D80: J136.2, U60.PA01
D+: J5.D+, U3.PA25
D+1: J9.D+, U6.PA25
D+2: J16.D+, U9.PA25
D+3: J23.D+, U12.PA25
D+4: J30.D+, U15.PA25
D+5: J37.D+, U18.PA25
D+6: J44.D+, U21.PA25
D+7: J51.D+, U24.PA25
D+8: J58.D+, U27.PA25
D+9: J65.D+, U30.PA25
D+10: J72.D+, U33.PA25
D+11: J79.D+, U36.PA25
D+12: J86.D+, U39.PA25
D+13: J93.D+, U42.PA25
D+14: J100.D+, U45.PA25
D+15: J107.D+, U48.PA25
D+16: J114.D+, U51.PA25
D+17: J121.D+, U54.PA25
D+18: J128.D+, U57.PA25
D+19: J135.D+, U60.PA25
D-: J5.D-, U3.PA24
D-1: J9.D-, U6.PA24
D-2: J16.D-, U9.PA24
D-3: J23.D-, U12.PA24
D-4: J30.D-, U15.PA24
D-5: J37.D-, U18.PA24
D-6: J44.D-, U21.PA24
D-7: J51.D-, U24.PA24
D-8: J58.D-, U27.PA24
D-9: J65.D-, U30.PA24
D-10: J72.D-, U33.PA24
D-11: J79.D-, U36.PA24
D-12: J86.D-, U39.PA24
D-13: J93.D-, U42.PA24
D-14: J100.D-, U45.PA24
D-15: J107.D-, U48.PA24
D-16: J114.D-, U51.PA24
D-17: J121.D-, U54.PA24
D-18: J128.D-, U57.PA24
D-19: J135.D-, U60.PA24
DAC: J3.7, U3.PA02
DAC1: J10.7, U6.PA02
DAC2: J17.7, U9.PA02
DAC3: J24.7, U12.PA02
DAC4: J31.7, U15.PA02
DAC5: J38.7, U18.PA02
DAC6: J45.7, U21.PA02
DAC7: J52.7, U24.PA02
DAC8: J59.7, U27.PA02
DAC9: J66.7, U30.PA02
DAC10: J73.7, U33.PA02
DAC11: J80.7, U36.PA02
DAC12: J87.7, U39.PA02
DAC13: J94.7, U42.PA02
DAC14: J101.7, U45.PA02
DAC15: J108.7, U48.PA02
DAC16: J115.7, U51.PA02
DAC17: J122.7, U54.PA02
DAC18: J129.7, U57.PA02
DAC19: J136.7, U60.PA02
FLASH_CS: R2.1, U2.1, U3.PA19
FLASH_CS1: R8.1, U5.1, U6.PA19
FLASH_CS2: R13.1, U8.1, U9.PA19
FLASH_CS3: R18.1, U11.1, U12.PA19
FLASH_CS4: R23.1, U14.1, U15.PA19
FLASH_CS5: R28.1, U17.1, U18.PA19
FLASH_CS6: R33.1, U20.1, U21.PA19
FLASH_CS7: R38.1, U23.1, U24.PA19
FLASH_CS8: R43.1, U26.1, U27.PA19
FLASH_CS9: R48.1, U29.1, U30.PA19
FLASH_CS10: R53.1, U32.1, U33.PA19
FLASH_CS11: R58.1, U35.1, U36.PA19
FLASH_CS12: R63.1, U38.1, U39.PA19
FLASH_CS13: R68.1, U41.1, U42.PA19
FLASH_CS14: R73.1, U44.1, U45.PA19
FLASH_CS15: R78.1, U47.1, U48.PA19
FLASH_CS16: R83.1, U50.1, U51.PA19
FLASH_CS17: R88.1, U53.1, U54.PA19
FLASH_CS18: R93.1, U56.1, U57.PA19
FLASH_CS19: R98.1, U59.1, U60.PA19
FLASH_MISO: U2.2, U3.PA18
FLASH_MISO1: U5.2, U6.PA18
FLASH_MISO2: U8.2, U9.PA18
FLASH_MISO3: U11.2, U12.PA18
FLASH_MISO4: U14.2, U15.PA18
FLASH_MISO5: U17.2, U18.PA18
FLASH_MISO6: U20.2, U21.PA18
FLASH_MISO7: U23.2, U24.PA18
FLASH_MISO8: U26.2, U27.PA18
FLASH_MISO9: U29.2, U30.PA18
FLASH_MISO10: U32.2, U33.PA18
FLASH_MISO11: U35.2, U36.PA18
FLASH_MISO12: U38.2, U39.PA18
FLASH_MISO13: U41.2, U42.PA18
FLASH_MISO14: U44.2, U45.PA18
FLASH_MISO15: U47.2, U48.PA18
FLASH_MISO16: U50.2, U51.PA18
FLASH_MISO17: U53.2, U54.PA18
FLASH_MISO18: U56.2, U57.PA18
FLASH_MISO19: U59.2, U60.PA18
FLASH_MOSI: U2.5, U3.PA16
FLASH_MOSI1: U5.5, U6.PA16
FLASH_MOSI2: U8.5, U9.PA16
FLASH_MOSI3: U11.5, U12.PA16
FLASH_MOSI4: U14.5, U15.PA16
FLASH_MOSI5: U17.5, U18.PA16
FLASH_MOSI6: U20.5, U21.PA16
FLASH_MOSI7: U23.5, U24.PA16
FLASH_MOSI8: U26.5, U27.PA16
FLASH_MOSI9: U29.5, U30.PA16
FLASH_MOSI10: U32.5, U33.PA16
FLASH_MOSI11: U35.5, U36.PA16
FLASH_MOSI12: U38.5, U39.PA16
FLASH_MOSI13: U41.5, U42.PA16
FLASH_MOSI14: U44.5, U45.PA16
FLASH_MOSI15: U47.5, U48.PA16
FLASH_MOSI16: U50.5, U51.PA16
FLASH_MOSI17: U53.5, U54.PA16
FLASH_MOSI18: U56.5, U57.PA16
FLASH_MOSI19: U59.5, U60.PA16
FLASH_SCK: U2.6, U3.PA17
FLASH_SCK1: U5.6, U6.PA17
FLASH_SCK2: U8.6, U9.PA17
FLASH_SCK3: U11.6, U12.PA17
FLASH_SCK4: U14.6, U15.PA17
FLASH_SCK5: U17.6, U18.PA17
FLASH_SCK6: U20.6, U21.PA17
FLASH_SCK7: U23.6, U24.PA17
FLASH_SCK8: U26.6, U27.PA17
FLASH_SCK9: U29.6, U30.PA17
FLASH_SCK10: U32.6, U33.PA17
FLASH_SCK11: U35.6, U36.PA17
FLASH_SCK12: U38.6, U39.PA17
FLASH_SCK13: U41.6, U42.PA17
FLASH_SCK14: U44.6, U45.PA17
FLASH_SCK15: U47.6, U48.PA17
FLASH_SCK16: U50.6, U51.PA17
FLASH_SCK17: U53.6, U54.PA17
FLASH_SCK18: U56.6, U57.PA17
FLASH_SCK19: U59.6, U60.PA17
GND: C1.2, C2.2, C3.2, C4.1, D2.C, D3.C, J1.1, J2.1, J4.2, J5.GND, J5.SHIELD, J5.SHIELD2, J5.SHIELD3, J5.SHIELD4, J5.SHIELD5, J5.SHIELD6, J5.SHIELD7, J5.SHIELD8, J5.SHIELD9, J5.SHIELD10, J6.1, R1.1, S2.1, S2.2, U1.2, U2.4, U3.GND, U3.GNDANA, U3.PAD
GND1: C5.1, C6.2, C7.2, C8.2, D4.C, D6.C, J8.1, J9.GND, J9.SHIELD, J9.SHIELD2, J9.SHIELD3, J9.SHIELD4, J9.SHIELD5, J9.SHIELD6, J9.SHIELD7, J9.SHIELD8, J9.SHIELD9, J9.SHIELD10, J12.1, J13.2, J14.1, R9.1, S4.1, S4.2, U4.2, U5.4, U6.GND, U6.GNDANA, U6.PAD
GND2: C9.1, C10.2, C11.2, C12.2, D7.C, D9.C, J15.1, J16.GND, J16.SHIELD, J16.SHIELD2, J16.SHIELD3, J16.SHIELD4, J16.SHIELD5, J16.SHIELD6, J16.SHIELD7, J16.SHIELD8, J16.SHIELD9, J16.SHIELD10, J19.1, J20.2, J21.1, R14.1, S6.1, S6.2, U7.2, U8.4, U9.GND, U9.GNDANA, U9.PAD
GND3: C13.1, C14.2, C15.2, C16.2, D10.C, D12.C, J22.1, J23.GND, J23.SHIELD, J23.SHIELD2, J23.SHIELD3, J23.SHIELD4, J23.SHIELD5, J23.SHIELD6, J23.SHIELD7, J23.SHIELD8, J23.SHIELD9, J23.SHIELD10, J26.1, J27.2, J28.1, R19.1, S8.1, S8.2, U10.2, U11.4, U12.GND, U12.GNDANA, U12.PAD
GND4: C17.1, C18.2, C19.2, C20.2, D13.C, D15.C, J29.1, J30.GND, J30.SHIELD, J30.SHIELD2, J30.SHIELD3, J30.SHIELD4, J30.SHIELD5, J30.SHIELD6, J30.SHIELD7, J30.SHIELD8, J30.SHIELD9, J30.SHIELD10, J33.1, J34.2, J35.1, R24.1, S10.1, S10.2, U13.2, U14.4, U15.GND, U15.GNDANA, U15.PAD
GND5: C21.1, C22.2, C23.2, C24.2, D16.C, D18.C, J36.1, J37.GND, J37.SHIELD, J37.SHIELD2, J37.SHIELD3, J37.SHIELD4, J37.SHIELD5, J37.SHIELD6, J37.SHIELD7, J37.SHIELD8, J37.SHIELD9, J37.SHIELD10, J40.1, J41.2, J42.1, R29.1, S12.1, S12.2, U16.2, U17.4, U18.GND, U18.GNDANA, U18.PAD
GND6: C25.1, C26.2, C27.2, C28.2, D19.C, D21.C, J43.1, J44.GND, J44.SHIELD, J44.SHIELD2, J44.SHIELD3, J44.SHIELD4, J44.SHIELD5, J44.SHIELD6, J44.SHIELD7, J44.SHIELD8, J44.SHIELD9, J44.SHIELD10, J47.1, J48.2, J49.1, R34.1, S14.1, S14.2, U19.2, U20.4, U21.GND, U21.GNDANA, U21.PAD
GND7: C29.1, C30.2, C31.2, C32.2, D22.C, D24.C, J50.1, J51.GND, J51.SHIELD, J51.SHIELD2, J51.SHIELD3, J51.SHIELD4, J51.SHIELD5, J51.SHIELD6, J51.SHIELD7, J51.SHIELD8, J51.SHIELD9, J51.SHIELD10, J54.1, J55.2, J56.1, R39.1, S16.1, S16.2, U22.2, U23.4, U24.GND, U24.GNDANA, U24.PAD
GND8: C33.1, C34.2, C35.2, C36.2, D25.C, D27.C, J57.1, J58.GND, J58.SHIELD, J58.SHIELD2, J58.SHIELD3, J58.SHIELD4, J58.SHIELD5, J58.SHIELD6, J58.SHIELD7, J58.SHIELD8, J58.SHIELD9, J58.SHIELD10, J61.1, J62.2, J63.1, R44.1, S18.1, S18.2, U25.2, U26.4, U27.GND, U27.GNDANA, U27.PAD
GND9: C37.1, C38.2, C39.2, C40.2, D28.C, D30.C, J64.1, J65.GND, J65.SHIELD, J65.SHIELD2, J65.SHIELD3, J65.SHIELD4, J65.SHIELD5, J65.SHIELD6, J65.SHIELD7, J65.SHIELD8, J65.SHIELD9, J65.SHIELD10, J68.1, J69.2, J70.1, R49.1, S20.1, S20.2, U28.2, U29.4, U30.GND, U30.GNDANA, U30.PAD
GND10: C41.1, C42.2, C43.2, C44.2, D31.C, D33.C, J71.1, J72.GND, J72.SHIELD, J72.SHIELD2, J72.SHIELD3, J72.SHIELD4, J72.SHIELD5, J72.SHIELD6, J72.SHIELD7, J72.SHIELD8, J72.SHIELD9, J72.SHIELD10, J75.1, J76.2, J77.1, R54.1, S22.1, S22.2, U31.2, U32.4, U33.GND, U33.GNDANA, U33.PAD
GND11: C45.1, C46.2, C47.2, C48.2, D34.C, D36.C, J78.1, J79.GND, J79.SHIELD, J79.SHIELD2, J79.SHIELD3, J79.SHIELD4, J79.SHIELD5, J79.SHIELD6, J79.SHIELD7, J79.SHIELD8, J79.SHIELD9, J79.SHIELD10, J82.1, J83.2, J84.1, R59.1, S24.1, S24.2, U34.2, U35.4, U36.GND, U36.GNDANA, U36.PAD
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

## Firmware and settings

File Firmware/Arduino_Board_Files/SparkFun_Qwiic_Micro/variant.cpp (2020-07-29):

/*
  Copyright (c) 2014-2015 Arduino LLC.  All right reserved.

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
  You should have received a copy of the GNU Lesser General Public
  License along with this library; if not, write to the Free Software
  Foundation, Inc., 51 Franklin St, Fifth Floor, Boston, MA  02110-1301  USA
*/


#include "variant.h"


// Pins descriptions
// ------------------------
const PinDescription g_APinDescription[] =
{
  // 0..8 - Digital pins
  // ----------------------
  { PORTA,  8, PIO_TIMER, (PIN_ATTR_DIGITAL|PIN_ATTR_PWM|PIN_ATTR_TIMER), ADC_Channel16, PWM0_CH0, TCC0_CH0, EXTERNAL_INT_NMI },      // D0/SDA
  { PORTA,  2, PIO_ANALOG, PIN_ATTR_ANALOG, ADC_Channel0, NOT_ON_PWM, NOT_ON_TIMER, EXTERNAL_INT_2 },                                 // D1/DAC
  { PORTA,  6, PIO_TIMER, (PIN_ATTR_DIGITAL|PIN_ATTR_PWM|PIN_ATTR_TIMER), ADC_Channel6, PWM1_CH0, TCC1_CH0, EXTERNAL_INT_6 },         // D2/MOSI
  { PORTA,  5, PIO_TIMER, (PIN_ATTR_DIGITAL|PIN_ATTR_PWM|PIN_ATTR_TIMER), ADC_Channel5, PWM0_CH1, TCC0_CH1, EXTERNAL_INT_5 },         // D3/MISO
  { PORTA,  7, PIO_TIMER, (PIN_ATTR_DIGITAL|PIN_ATTR_PWM|PIN_ATTR_TIMER), ADC_Channel7, PWM1_CH1, TCC1_CH1, EXTERNAL_INT_7 },         // D4/SCK
  { PORTA,  0, PIO_DIGITAL, PIN_ATTR_DIGITAL, No_ADC_Channel, NOT_ON_PWM, TCC2_CH0, EXTERNAL_INT_0 },                                 // D5
  { PORTA,  1, PIO_DIGITAL, PIN_ATTR_DIGITAL, No_ADC_Channel, NOT_ON_PWM, TCC2_CH1, EXTERNAL_INT_1 },                                 // D6
  { PORTA,  4, PIO_TIMER, (PIN_ATTR_DIGITAL|PIN_ATTR_PWM|PIN_ATTR_TIMER), ADC_Channel4,PWM0_CH0,  TCC0_CH0, EXTERNAL_INT_4 },         // D7/VREFB
  { PORTA,  9, PIO_TIMER, (PIN_ATTR_DIGITAL|PIN_ATTR_PWM|PIN_ATTR_TIMER), ADC_Channel17, PWM0_CH1, TCC0_CH1, EXTERNAL_INT_9 },        // D8/SCL

  // 9/10 - I2C 
  // ----------------------
  { PORTA,  8, PIO_SERCOM_ALT, (PIN_ATTR_DIGITAL|PIN_ATTR_PWM|PIN_ATTR_TIMER), ADC_Channel16, PWM0_CH0, TCC0_CH0, EXTERNAL_INT_NMI }, // SDA/D0
  { PORTA,  9, PIO_SERCOM_ALT, (PIN_ATTR_DIGITAL|PIN_ATTR_PWM|PIN_ATTR_TIMER), ADC_Channel17, PWM0_CH1, TCC0_CH1, EXTERNAL_INT_9 },   // SCL/D2
  
  // 11..15 - SPI
  // --------------------
  { PORTA,  7, PIO_SERCOM_ALT, (PIN_ATTR_DIGITAL|PIN_ATTR_PWM|PIN_ATTR_TIMER), ADC_Channel7, PWM1_CH1, TCC1_CH1, EXTERNAL_INT_7 },    // SCK/D11
  { PORTA,  3, PIO_ANALOG, PIN_ATTR_ANALOG, ADC_Channel11, NOT_ON_PWM, NOT_ON_TIMER, EXTERNAL_INT_3 },                                // D12
  { PORTA, 10, PIO_DIGITAL, (PIN_ATTR_DIGITAL|PIN_ATTR_PWM|PIN_ATTR_TIMER), ADC_Channel18, PWM1_CH0,  TCC1_CH0, EXTERNAL_INT_10},     // D13/LED
  { PORTA,  6, PIO_SERCOM_ALT, (PIN_ATTR_DIGITAL|PIN_ATTR_PWM|PIN_ATTR_TIMER), ADC_Channel6, PWM1_CH0, TCC1_CH0, EXTERNAL_INT_6 },    // MOSI/D14
  { PORTA,  5, PIO_SERCOM_ALT, (PIN_ATTR_DIGITAL|PIN_ATTR_PWM|PIN_ATTR_TIMER), ADC_Channel5,PWM0_CH1,  TCC0_CH1, EXTERNAL_INT_5 },    // MISO/D15

  // 16/17 - RX/TX 
  // --------------------
  { PORTA, 23, PIO_SERCOM, (PIN_ATTR_DIGITAL|PIN_ATTR_PWM|PIN_ATTR_TIMER), No_ADC_Channel, PWM4_CH1, TC4_CH1, EXTERNAL_INT_7 },       // TX/D16
  { PORTA, 22, PIO_SERCOM, (PIN_ATTR_DIGITAL|PIN_ATTR_PWM|PIN_ATTR_TIMER), No_ADC_Channel, PWM4_CH0, TC4_CH0, EXTERNAL_INT_6 },       // RX/D17

  // 18-21 - Flash SPI
  // --------------------
  { PORTA, 16, PIO_SERCOM, (PIN_ATTR_DIGITAL|PIN_ATTR_PWM|PIN_ATTR_TIMER), No_ADC_Channel, PWM2_CH0, TCC2_CH0, EXTERNAL_INT_0 },      // Flash MOSI
  { PORTA, 17, PIO_SERCOM, (PIN_ATTR_DIGITAL|PIN_ATTR_PWM|PIN_ATTR_TIMER), No_ADC_Channel, PWM2_CH1, TCC2_CH1, EXTERNAL_INT_1 },      // Flash SCK
  { PORTA, 18, PIO_SERCOM, (PIN_ATTR_DIGITAL|PIN_ATTR_PWM|PIN_ATTR_TIMER), No_ADC_Channel, PWM3_CH0, TC3_CH0, EXTERNAL_INT_2 },       // Flash MISO
  { PORTA, 19, PIO_SERCOM, (PIN_ATTR_DIGITAL|PIN_ATTR_PWM|PIN_ATTR_TIMER), No_ADC_Channel, PWM3_CH1, TC3_CH1, EXTERNAL_INT_3 },       // Flash SS

  // 22/23 - SWD 
  // --------------------
  { PORTA, 30, PIO_TIMER, (PIN_ATTR_DIGITAL|PIN_ATTR_PWM|PIN_ATTR_TIMER), No_ADC_Channel, PWM1_CH0, TCC1_CH0, EXTERNAL_INT_10 },      // SWCLK/D22 
  { PORTA, 31, PIO_TIMER, (PIN_ATTR_DIGITAL|PIN_ATTR_PWM|PIN_ATTR_TIMER), No_ADC_Channel, PWM1_CH1, TCC1_CH1, EXTERNAL_INT_11 },      // SWDIO/D23

  // 24..29, A0-A5 - Analog pins
  // --------------------
  { PORTA,  2, PIO_ANALOG, PIN_ATTR_ANALOG, ADC_Channel0, NOT_ON_PWM, NOT_ON_TIMER, EXTERNAL_INT_2 },                                 // A0/D1/DAC
  { PORTA,  6, PIO_ANALOG, (PIN_ATTR_DIGITAL|PIN_ATTR_PWM|PIN_ATTR_TIMER), ADC_Channel6, PWM1_CH0, TCC1_CH0, EXTERNAL_INT_6 },        // A1/D2
  { PORTA,  5, PIO_ANALOG, (PIN_ATTR_DIGITAL|PIN_ATTR_PWM|PIN_ATTR_TIMER), ADC_Channel5, PWM0_CH1, TCC0_CH1, EXTERNAL_INT_5 },        // A2/D3
  { PORTA,  7, PIO_ANALOG, (PIN_ATTR_DIGITAL|PIN_ATTR_PWM|PIN_ATTR_TIMER), ADC_Channel7, PWM1_CH1, TCC1_CH1, EXTERNAL_INT_7 },        // A3/D4
  { PORTA, 10, PIO_ANALOG, (PIN_ATTR_DIGITAL|PIN_ATTR_PWM|PIN_ATTR_TIMER), ADC_Channel18, PWM1_CH0, TCC1_CH0, EXTERNAL_INT_10 },      // A4/D13
  { PORTA,  4, PIO_ANALOG, (PIN_ATTR_DIGITAL|PIN_ATTR_PWM|PIN_ATTR_TIMER), ADC_Channel4, PWM0_CH0, TCC0_CH0, EXTERNAL_INT_4 },        // A5/D6

  // 30..32 - USB
  // --------------------
  { PORTA, 28, PIO_COM, PIN_ATTR_NONE, No_ADC_Channel, NOT_ON_PWM, NOT_ON_TIMER, EXTERNAL_INT_NONE },                                 // usb hOST ENABLE
  { PORTA, 24, PIO_COM, PIN_ATTR_NONE, No_ADC_Channel, NOT_ON_PWM, NOT_ON_TIMER, EXTERNAL_INT_NONE },                                 // usb/dm
  { PORTA, 25, PIO_COM, PIN_ATTR_NONE, No_ADC_Channel, NOT_ON_PWM, NOT_ON_TIMER, EXTERNAL_INT_NONE },                                 // usb/dp

  // 33..35 - Unused Pins
  // ----------------------
  { PORTA, 11, PIO_TIMER, (PIN_ATTR_DIGITAL|PIN_ATTR_PWM|PIN_ATTR_TIMER), ADC_Channel19, PWM1_CH1, TCC1_CH1, EXTERNAL_INT_11 },
  { PORTA, 14, PIO_TIMER, (PIN_ATTR_DIGITAL|PIN_ATTR_PWM|PIN_ATTR_TIMER), No_ADC_Channel, PWM3_CH0, TC3_CH0, EXTERNAL_INT_14 },
  { PORTA, 15, PIO_TIMER, (PIN_ATTR_DIGITAL|PIN_ATTR_PWM|PIN_ATTR_TIMER), No_ADC_Channel, PWM3_CH1, TC3_CH1, EXTERNAL_INT_15 }

};

const void* g_apTCInstances[TCC_INST_NUM+TC_INST_NUM]={ TCC0, TCC1, TCC2, TC3, TC4, TC5 } ;

// Multi-serial objects instantiation
SERCOM sercom0( SERCOM0 ) ;
SERCOM sercom1( SERCOM1 ) ;
SERCOM sercom2( SERCOM2 ) ;
SERCOM sercom3( SERCOM3 ) ;


Uart Serial( &sercom3, PIN_SERIAL_RX, PIN_SERIAL_TX, PAD_SERIAL_RX, PAD_SERIAL_TX ) ;

void SERCOM3_Handler()
{
  Serial.IrqHandler();
}

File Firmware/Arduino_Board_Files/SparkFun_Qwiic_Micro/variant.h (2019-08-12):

/*
  Copyright (c) 2014-2015 Arduino LLC.  All right reserved.

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
  You should have received a copy of the GNU Lesser General Public
  License along with this library; if not, write to the Free Software
  Foundation, Inc., 51 Franklin St, Fifth Floor, Boston, MA  02110-1301  USA
*/

#ifndef _VARIANT_ARDUINO_ZERO_
#define _VARIANT_ARDUINO_ZERO_

// The definitions here needs a SAMD core >=1.6.6
#define ARDUINO_SAMD_VARIANT_COMPLIANCE 10606

/*----------------------------------------------------------------------------
 *        Definitions
 *----------------------------------------------------------------------------*/

/** Frequency of the board main oscillator */
#define VARIANT_MAINOSC		(32768ul)

/** Master clock frequency */
#define VARIANT_MCK			  (F_CPU)

/*----------------------------------------------------------------------------
 *        Headers
 *----------------------------------------------------------------------------*/

#include "WVariant.h"

#ifdef __cplusplus
#include "SERCOM.h"
#include "Uart.h"
#endif // __cplusplus

#ifdef __cplusplus
extern "C"
{
#endif // __cplusplus

/*----------------------------------------------------------------------------
 *        Pins
 *----------------------------------------------------------------------------*/

// Number of pins defined in PinDescription array
#define PINS_COUNT           (36u)
#define NUM_DIGITAL_PINS     (30u)
#define NUM_ANALOG_INPUTS    (6u)
#define NUM_ANALOG_OUTPUTS   (1u)
#define analogInputToDigitalPin(p)  ((p < 6u) ? (p) + 22u : -1)

#define digitalPinToPort(P)        ( &(PORT->Group[g_APinDescription[P].ulPort]) )
#define digitalPinToBitMask(P)     ( 1 << g_APinDescription[P].ulPin )
//#define analogInPinToBit(P)        ( )
#define portOutputRegister(port)   ( &(port->OUT.reg) )
#define portInputRegister(port)    ( &(port->IN.reg) )
#define portModeRegister(port)     ( &(port->DIR.reg) )
#define digitalPinHasPWM(P)        ( g_APinDescription[P].ulPWMChannel != NOT_ON_PWM || g_APinDescription[P].ulTCChannel != NOT_ON_TIMER )

/*
 * digitalPinToTimer(..) is AVR-specific and is not defined for SAMD
 * architecture. If you need to check if a pin supports PWM you must
 * use digitalPinHasPWM(..).
 *
 * https://github.com/arduino/Arduino/issues/1833
 */
// #define digitalPinToTimer(P)

// RX and TX LEDs are not present on the board. 
#define PIN_LED_13           (13u)
#define PIN_LED_RXL          (25u)
#define PIN_LED_TXL          (26u)
#define PIN_LED              PIN_LED_13
#define PIN_LED2             PIN_LED_RXL
#define PIN_LED3             PIN_LED_TXL
#define LED_BUILTIN          PIN_LED_13

/*
 * Analog pins
 */
#define PIN_A0               (24u)
#define PIN_A1               (PIN_A0+1)
#define PIN_A2               (PIN_A0+2)
#define PIN_A3               (PIN_A0+3)
#define PIN_A4               (PIN_A0+4)
#define PIN_A5               (PIN_A0+5)
#define PIN_DAC0             PIN_A0

static const uint8_t A0  = PIN_A0;
static const uint8_t A1  = PIN_A1;
static const uint8_t A2  = PIN_A2;
static const uint8_t A3  = PIN_A3;
static const uint8_t A4  = PIN_A4;
static const uint8_t A5  = PIN_A5;
static const uint8_t DAC0 = PIN_DAC0;
#define ADC_RESOLUTION		12

/*
 * Serial interfaces
 */

// Serial
#define PIN_SERIAL_TX       (16ul)
#define PIN_SERIAL_RX       (17ul)
#define PAD_SERIAL_TX       (UART_TX_PAD_0)
#define PAD_SERIAL_RX       (SERCOM_RX_PAD_1)

/*
 * SPI Interfaces
 */
#define SPI_INTERFACES_COUNT 2

#define PIN_SPI_MOSI         (14u)
#define PIN_SPI_MISO         (15u)
#define PIN_SPI_SCK          (11u)
#define PIN_SPI_SS			     (7u)
#define PERIPH_SPI           sercom0
#define PAD_SPI_TX           SPI_PAD_2_SCK_3
#define PAD_SPI_RX           SERCOM_RX_PAD_1

static const uint8_t SS	  = PIN_SPI_SS ;
static const uint8_t MOSI = PIN_SPI_MOSI ;
static const uint8_t MISO = PIN_SPI_MISO ;
static const uint8_t SCK  = PIN_SPI_SCK ;

#define PIN_SPI1_MOSI         (18u)
#define PIN_SPI1_SCK          (19u)
#define PIN_SPI1_MISO         (20u)
#define PIN_SPI1_SS		        (21u)
#define PERIPH_SPI1           sercom1
#define PAD_SPI1_TX           SPI_PAD_0_SCK_1
#define PAD_SPI1_RX           SERCOM_RX_PAD_2

static const uint8_t FLASH_SS   = PIN_SPI1_SS ;	
static const uint8_t FLASH_MOSI = PIN_SPI1_MOSI ;
static const uint8_t FLASH_MISO = PIN_SPI1_MISO ;
static const uint8_t FLASH_SCK  = PIN_SPI1_SCK ;

/*
 * Wire Interfaces
 */
//I2C/Qwiic Interface
#define WIRE_INTERFACES_COUNT 1

#define PIN_WIRE_SDA         (9u)
#define PIN_WIRE_SCL         (10u)
#define PERIPH_WIRE          sercom2
#define WIRE_IT_HANDLER      SERCOM2_Handler

static const uint8_t SDA = PIN_WIRE_SDA;
static const uint8_t SCL = PIN_WIRE_SCL;

/*
 * USB
 */
#define PIN_USB_HOST_ENABLE (30ul)
#define PIN_USB_DM          (31ul)
#define PIN_USB_DP          (32ul)


#ifdef __cplusplus
}
#endif

/*----------------------------------------------------------------------------
 *        Arduino objects - C++ only
 *----------------------------------------------------------------------------*/

#ifdef __cplusplus

/*	=========================
 *	===== SERCOM DEFINITION
 *	=========================
*/
extern SERCOM sercom0;
extern SERCOM sercom1;
extern SERCOM sercom2;
extern SERCOM sercom3;


extern Uart Serial;


#endif

// These serial port names are intended to allow libraries and architecture-neutral
// sketches to automatically default to the correct port name for a particular type
// of use.  For example, a GPS module would normally connect to SERIAL_PORT_HARDWARE_OPEN,
// the first hardware serial port whose RX/TX pins are not dedicated to another use.
//
// SERIAL_PORT_MONITOR        Port which normally prints to the Arduino Serial Monitor
//
// SERIAL_PORT_USBVIRTUAL     Port which is USB virtual serial
//
// SERIAL_PORT_LINUXBRIDGE    Port which connects to a Linux system via Bridge library
//
// SERIAL_PORT_HARDWARE       Hardware serial port, physical RX & TX pins.
//
// SERIAL_PORT_HARDWARE_OPEN  Hardware serial ports which are open for use.  Their RX & TX
//                            pins are NOT connected to anything by default.
#define SERIAL_PORT_USBVIRTUAL      SerialUSB
#define SERIAL_PORT_MONITOR         SerialUSB
#define SERIAL_PORT_HARDWARE        Serial
#define SERIAL_PORT_HARDWARE_OPEN   Serial

#endif /* _VARIANT_ARDUINO_ZERO_ */

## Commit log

2019-07-22 Initial Commit - Moves files from old repo
    [QwiicMicocontroller-Panel.brd, QwiicMicro.csv, SparkFun_Qwiic_Micro_SAMD21E.brd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]
2019-07-22 Improves all silk, replaces 0603 resistor with 0402, updates trace work for better ground pour
    [SparkFun_Qwiic_Micro_SAMD21E.brd, SparkFun_Qwiic_Micro_SAMD21E.sch]
2019-07-23 Moves some traces
    [SparkFun_Qwiic_Micro_SAMD21E.brd, SparkFun_Qwiic_Micro_SAMD21E.sch]
2019-07-23 Updates micro-controller symbol with Arduino digital pin assignments
    * replaces lipo battery symbol with better one
    * Re-adds battery line test ponit
    * Removes info text about Arduino pin assignments
    * Improves notes on SERCOM ports
    * Re-numbers all parts
    * Removes test library - no longer needed.
    [SparkFun_Qwiic_Micro_SAMD21E.brd, SparkFun_Qwiic_Micro_SAMD21E.sch]
2019-07-23 Updates microcontroller symbol
    [SparkFun_Qwiic_Micro_SAMD21E.brd, SparkFun_Qwiic_Micro_SAMD21E.sch]
2019-07-23 Moves some text around
    [SparkFun_Qwiic_Micro_SAMD21E.brd, SparkFun_Qwiic_Micro_SAMD21E.sch]
2019-07-23 Attaches analog voltage pin to 3.3V power rail
    [SparkFun_Qwiic_Micro_SAMD21E.brd, SparkFun_Qwiic_Micro_SAMD21E.sch]
2019-07-24 Moves silk around in various spots, rotates LED to make space for PWR silk
    [SparkFun_Qwiic_Micro_SAMD21E.brd, trinket_m0.cfg]
2019-07-25 Updates numbering on samd21E
    [SparkFun_Qwiic_Micro_SAMD21E.brd, SparkFun_Qwiic_Micro_SAMD21E.sch]
2019-07-26 Huge update
    * Changes pin layout in arduino files which are now reflected in SAMD21 symbol
    * reroutes different lines to the headers on the left side of the board
    * removes the APA102 in favor of blue stat LED
    * Changes Qwiic Micro Arduino pin order and internal APA102 pin assignments
    * Adds gerbers
    [QwiicMicocontroller-Panel.brd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]
2019-08-12 New bootloader, updates samd21 with latest package
    [SparkFun_Qwiic_Micro_SAMD21E.brd, SparkFun_Qwiic_Micro_SAMD21E.sch]
2019-08-12 Fixes SPI (wrong pins given to SPI defines)
    [variant.h]
2019-08-13 Moves the EEPROM chip and Lipo connector away from each other every so slightly.
    [SparkFun_Qwiic_Micro_SAMD21E.brd]
2019-08-14 Moves 10k pull-up resistor on Flash CS line to top layer.
    [SparkFun_Qwiic_Micro_SAMD21E.brd, SparkFun_Qwiic_Micro_SAMD21E.sch]
2019-08-14 Updates dimensions...
    [SparkFun_Qwiic_Micro_SAMD21E.brd, SparkFun_Qwiic_Micro_SAMD21E.sch]
2019-08-15 Adds Circuit Python build files.
2019-08-16 Adds VCC ranges, Adds note for optional parts
    [SparkFun_Qwiic_Micro_SAMD21E.sch]
2019-08-16 Moves wondering text
    [SparkFun_Qwiic_Micro_SAMD21E.sch]
2019-08-16 Adds updated Production Files
    [SparkFun_Qwiic_Micro_SAMD21E-Panel.brd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]
2019-08-19 Updates Ignore pins in Circuit Python build
    * Changes USB PID to 0x8D24
    * Adds SUPEROPT flag
    * Adds UART pins to mpconfigboard.h
2019-08-19 Changes linker file selection for circuit python build, and adds flash spi for CP build as well
2019-08-19 Adds a uf2 and elf file for a circuit python build using flash on the underside.
2019-08-19 Updates file structure, creates circuit python build if user does not have their own flash
2019-08-19 Adds circuit python firmware for those that do not use a flash.
2019-10-09 Adds new production files with correct design rules
    [SparkFun_Qwiic_Micro_SAMD21E-Panel.GBL, SparkFun_Qwiic_Micro_SAMD21E-Panel.GBO, SparkFun_Qwiic_Micro_SAMD21E-Panel.GBP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]
2019-10-23 Adds corrected Graphical Datasheet
    [QwiicMicro.csv]
2019-10-25 Move Graphical Datasheet
    Moving to GitHub Repo => https://github.com/sparkfun/Graphical_Datasheets/tree/master/Datasheets/SAM21
    [QwiicMicro.csv]
2020-07-28 Update variant.cpp
    Fixed the misordered pins 16 and 17
    [variant.cpp]
2021-04-05 Swaps "D16/D17" symbol names
    [SparkFun_Qwiic_Micro_SAMD21E.brd, SparkFun_Qwiic_Micro_SAMD21E.sch]

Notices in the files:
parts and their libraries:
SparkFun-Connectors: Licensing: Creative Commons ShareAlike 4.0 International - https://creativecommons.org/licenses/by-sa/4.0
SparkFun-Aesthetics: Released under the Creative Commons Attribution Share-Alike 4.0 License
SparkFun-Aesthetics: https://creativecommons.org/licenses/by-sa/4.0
